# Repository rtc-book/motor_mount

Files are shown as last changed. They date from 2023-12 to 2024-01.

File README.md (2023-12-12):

# Motor Mount

This is a motor mount for the T1a target system for _An Introduction to Real-Time Computing for Mechanical Engineers_ book by Picone, Garbini, and Devine.

### Construction

It is suggested to construct this motor mount by 3D printing the model contained in this repository, then assembling it using the parts and instructions below.

### Parts List

| Part | Number | Source |
| --- | --- | --- |
| Motor Mount | 1 | 3D print [mount.stl](mount.stl) |
| 8-32 Hex Nuts | 3 | McMaster Carr P/N 90480A009 or equivalent |
| 8-32 x 3/8 Screw | 2 | McMaster Carr P/N 92220A152 or equivalent |
| 8-32 x 1/4 Nylon Tip Set Screw | 1 | McMaster Carr P/N 94115A190 or equivalent |

### Installation Instructions

1. Place one hex nut into the hexagonal pocket inside the main bore.
2. Slide the motor into the main bore with the encoder pins pointed in the same directions as the three holes.
3. Thread the set screw into the center hole, but **do not tighten**.
4. Slide one hex nut into each of the side pockets.
5. Plug the encoder into its plug on the T1a electromechanical subsystem circuit board.
6. Slide the motor mount along the motor until the mounting holes line up with the holes in the circuit board.
7. Place a screw in each of the two outer holes and tighten.
8. Tighten the set screw accessible via the middle hole.

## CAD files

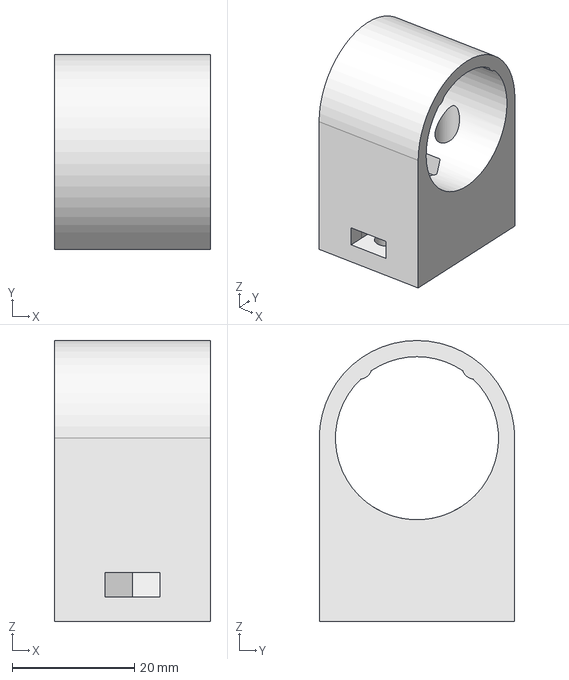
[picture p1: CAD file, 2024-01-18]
mount.FCStd
25.6 x 32.0 x 46.0 mm

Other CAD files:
mount.stl

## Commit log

2023-12-11 first draft motor mount
    [mount.scad, mount.stl]
2023-12-11 updated motor mount
    [mount.FCStd, mount.stl]
2023-12-12 removing old version
    [mount.scad]
2024-01-18 modified main bore dia and changed clamping geometry
    [mount.FCStd, mount.stl]
